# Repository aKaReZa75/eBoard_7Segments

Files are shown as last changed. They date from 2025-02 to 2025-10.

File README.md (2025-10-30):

# 7Segment Shield
This project involves designing, assembling, and testing an Arduino shield with a 7-segment display. The board includes a 7-segment display, push buttons, and an Oled display.

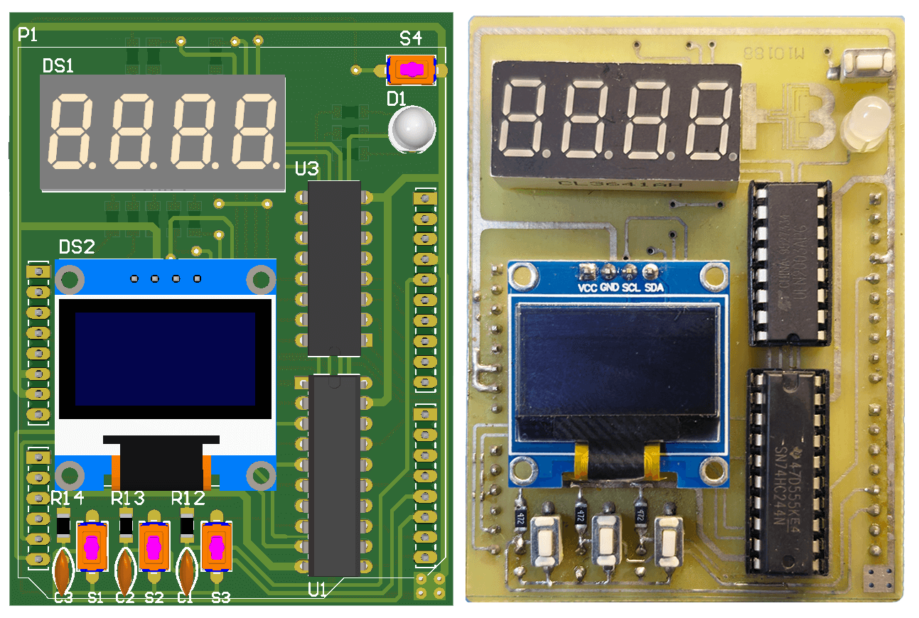
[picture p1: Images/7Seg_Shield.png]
7Segment Shield


> [!IMPORTANT]
> Before sending the board files for PCB fabrication, **always make sure you are using the latest released version** of the project.
> Hardware issues or design flaws might exist in earlier versions and could be fixed in newer releases.
> To avoid costly mistakes and ensure the best performance, always refer to the **[Releases](../../releases)** section, where all known issues, updates, and version-specific notes are clearly documented.

<table>
  <tr>
  <td valign="top">
  
  > [!TIP]  
  > If you're looking to better understand how to navigate and use my GitHub repositories — including exploring their structure, downloading or cloning projects, submitting issues, and asking questions,  
  > everything you need is clearly explained in this video:  
  > [aKaReZa 95 - Programming, Git - PART B](https://youtu.be/zYiUItVFRqQ)  
  > Make sure to check it out!
  
  </td>
    <td width="360" valign="middle" style="padding: 0;">
      <a href="https://youtu.be/zYiUItVFRqQ">
       aKaReZa 95 - Programming, Git - PART B Thumbnail
      </a>
    </td>
  </td>
  </tr>

<tr>
  <td valign="top">
  
  > [!IMPORTANT]
  > Begin your embedded systems journey with clarity and purpose. This episode outlines a structured roadmap for mastering microcontrollers, communication protocols, hardware design, and project development.  
  > Learn how to choose your specialization, follow curated playlists, and engage effectively with the community—ideal for learners seeking a scalable, goal-driven path into embedded engineering.  
  > [aKaReZa 124 – Embedded Systems Roadmap](https://youtu.be/3QYfv7A7aMc)  
  > Watch it now to kickstart your journey!
  
  </td>
  <td width="360" valign="middle" style="padding: 0;">
    <a href="https://youtu.be/3QYfv7A7aMc">
      aKaReZa 124 – Embedded Systems Roadmap Thumbnail
    </a>
  </td>
</tr>

  <tr>
  <td colspan="3">

  > [!CAUTION]
  > It is absolutely critical that you carefully read every single word of this document, line by line, to ensure you don't miss any details. Nothing can be overlooked.
      
  </td>
  </tr>  
</table>

## Detailed Description
| Aspect | Description |
|---|---|
| PCB Design Software  | Altium  V24.2.2 |
| PCB Layers | 2-Layer FR4 |
| Pin Type | Arduino UNO |
| 7Segment | CC - MPX4 - 30.2x14.1mm |
| Oled | SSD1306 - 0.96" - 128X64 - I2C |
| PushButtom | SMT Tactile 2PIN - SPST - 6X3X2 |

## **Pinout Mapping Table**
| **Shield Pin** | **Arduino Pin** | **ATmega328P Pin** | **STM32F103C8T6 Pin** |
| :---: | :---: | :---: | :---: |
| **Segment A (7-Segment)** | A0 | PC0 | PA0 |
| **Segment B (7-Segment)** | A1 | PC1 | PA1 |
| **Segment C (7-Segment)** | A2 | PC2 | PA2 |
| **Segment D (7-Segment)** | A3 | PC3 | PA3 |
| **Segment E (7-Segment)** | D0 | PD0 | PB11 |
| **Segment F (7-Segment)** | D1 | PD1 | PB10 |
| **Segment G (7-Segment)** | D4 | PD4 | PA7 |
| **Decimal Point (7-Segment)** | D7 | PD7 | PA9 |
|  **Digit 1 (Common Cathode)** | D8 | PB0 | PA15 |
|  **Digit 2 (Common Cathode)** | D9 | PB1 | PA8 |
|  **Digit 3 (Common Cathode)** | D10 | PB2 | PB12 |
|  **Digit 4 (Common Cathode)** | D12 | PB4 | PB14 |
| **Switch 1 (Active High)**  | D13 | PB5 | PB13 |
| **Switch 2 (Active High)**  | D3 | PD3 | PA6 |
| **Switch 3 (Active High)**  | D2 | PD2 | PB2 |
|  **RGB Green (Active High)**  | D5 | PD5 | PB0 |
| **RGB Blue (Active High)**  | D6 | PD6 | PB1 |
| **RGB RED (Active High)** | D11 | PB3 | PB15 |
| **Serial Data (SDA)** | A4 | PC4 | PB9 |
| **Serial Clock (SCL)** | A5 | PC5 | PB8 |

## Resources

> [!TIP]
> The resources are detailed in the sections below.  
> To access any of them, simply click on the corresponding blue link.

- [Altium Library](https://github.com/aKaReZa75/Altium-Library)  
  ---  
   All PCB designs across all repositories and projects are built using this Altium Designer component library. It contains a wide range of verified footprints, schematic symbols, and 3D models, ensuring consistency and accuracy in PCB designs. If you're working on a new PCB, using this library will save you time and minimize errors.

- [PCB & Electronics Design Training](https://github.com/aKaReZa75/PCB)  
  ---  
  This repository is dedicated to **learning PCB design and electronics from scratch**. It covers everything from circuit theory to practical PCB layout techniques, including routing strategies, best practices, and component placement. Whether you're a beginner or an experienced designer, this resource will help you **improve your PCB design skills and create professional-quality boards**.

- [Microcontroller Training](https://github.com/aKaReZa75/Microcontroller)  
  ---  
  This repository offers a comprehensive guide to learning **various microcontrollers** and how to interface them with different shields. You’ll find tutorials on **using and configuring shields**, along with hands-on projects to help you **get your microcontrollers up and running**. Whether you're working with **Arduino, STM32, ESP32**, or others, this resource will help you understand how to integrate these platforms effectively for your projects.

- [Shopping Link](./ShoppingLink.md)  
  ---
  This document provides links to trusted suppliers where you can purchase all the essential components for this project, ensuring quality and reliability.

```plaintext
Arduino Shields
   ├── [aKaReZa 36 - eBoard, 7Segment Shield - Part A]
   │   ├─ PCB Design — Two-layer Arduino shield with displays and buttons.
   │   ├─ Components — 74HC244, ULN2003, OLED, 7-segment, push buttons.
   │   └─ Layout — Schematic, placement, routing + Altium automation.
   │
   ├── [aKaReZa 40 - eBoard, 7Segment Shield - Part B]
   │   ├─ Troubleshooting — Routing issues and manual optimizations.
   │   └─ Review — Vias, GND problems, and connectivity fixes.
   │
   └── [aKaReZa 42 - Repair, Arduino 7Segment Shield Soldering]
       ├─ Assembly — Soldering tools, SMD + THD techniques.
       └── Components — ICs, buttons, displays, RGB LEDs, pin headers.
```     

## Project Videos
<table style="border-collapse: collapse;">
  <tr>
    <td valign="top" style="padding: 0 10px;">
      <h3 style="margin: 0;">
        <a href="https://youtu.be/BtFFsqzkCSk">aKaReZa 36 – PCB, 7Segment Shield - Part A</a>
      </h3>
      <p style="margin: 8px 0 0;">
        In this video, we design our first double-layer PCB. The board we design is an Arduino shield that includes a 7-segment display, push buttons, and an Oled display.
      </p>
    </td>
    <td width="360" valign="top" style="padding: 0;">
      <a href="https://youtu.be/BtFFsqzkCSk">
        aKaReZa 36 – PCB, 7Segment Shield - Part A Thumbnail
      </a>
    </td>
  </tr>

  <tr>
    <td valign="top" style="padding: 0 10px;">
      <h3 style="margin: 0;">
        <a href="https://youtu.be/yqlKacCi0RM">aKaReZa 40 – PCB, 7Segment Shield - Part B</a>
      </h3>
      <p style="margin: 8px 0 0;">
        In this video, we examine the issues with the 7-segment and Oled Arduino shield we designed in the previous video, which was routed using Auto Route. We review the problems and discuss manual routing along with important tips to follow during manual routing.
      </p>
    </td>
    <td width="360" valign="top" style="padding: 0;">
      <a href="https://youtu.be/yqlKacCi0RM">
        aKaReZa 40 – PCB, 7Segment Shield - Part B Thumbnail
      </a>
    </td>
  </tr>

  <tr>
    <td valign="top" style="padding: 0 10px;">
      <h3 style="margin: 0;">
        <a href="https://youtu.be/1Rpm_uHoqAg">aKaReZa 42 – Repair, Arduino 7Segment Shield Soldering</a>
      </h3>
      <p style="margin: 8px 0 0;">
        In this video, we assemble the 7-segment and OLED shield we designed after printing it, and we learn several important tips about proper soldering techniques for SMD and THD components.
      </p>
    </td>
    <td width="360" valign="top" style="padding: 0;">
      <a href="https://youtu.be/1Rpm_uHoqAg">
        aKaReZa 42 – Repair, Arduino 7Segment Shield Soldering Thumbnail
      </a>
    </td>
  </tr>
</table>

# 💻 How to Use Git and GitHub
To access the repository files and save them on your computer, there are two methods available:
1. **Using Git Bash and Cloning the Repository**
   - This method is more suitable for advanced users and those familiar with command-line tools.
   - By using this method, you can easily receive updates for the repository.

2. **Downloading the Repository as a ZIP file**
   - This method is simpler and suitable for users who are not comfortable with command-line tools.
   - Note that with this method, you will not automatically receive updates for the repository and will need to manually download any new updates.

## Clone using the URL.
First, open **Git Bash** :
-  Open the folder in **File Explorer** where you want the library to be stored.
-  **Right-click** inside the folder and select the option **"Open Git Bash here"** to open **Git Bash** in that directory.

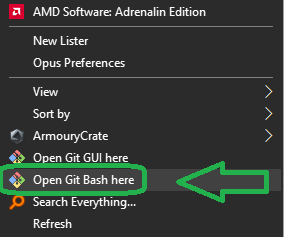
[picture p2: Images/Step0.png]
open Git Bash


> [!NOTE] 
> If you do not see the "Open Git Bash here" option, it means that Git is not installed on your system.  
> You can download and install Git from [this link](https://git-scm.com/downloads).  
> For a tutorial on how to install and use Git, check out [this video](https://youtu.be/BsykgHpmUt8).
  
-  Once **Git Bash** is open, run the following command to clone the repository:

 ```bash
git clone https://github.com/aKaReZa75/eBoard_7Segments.git
```
- You can copy the above command by either:
- Clicking on the **Copy** button on the right of the command.
- Or select the command text manually and press **Ctrl + C** to copy.
- To paste the command into your **Git Bash** terminal, use **Shift + Insert**.

Clone the Repository

- Then, press Enter to start the cloning operation and wait for the success message to appear.

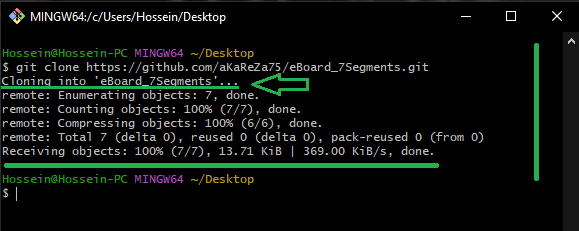
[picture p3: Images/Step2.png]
Open the Library File


> [!IMPORTANT]
> Please keep in mind that the numbers displayed in the image might vary when you perform the same actions.  
> This is because repositories are continuously being updated and expanded. Nevertheless, the overall process remains unchanged.

> [!NOTE]
> Advantage of Cloning the Repository:  
> - **Receiving Updates:** By cloning the repository, you can easily and automatically receive new updates.  
> - **Version Control:** Using Git allows you to track changes and revert to previous versions.  
> - **Team Collaboration:** If you are working on a project with a team, you can easily sync changes from team members and collaborate more efficiently.  

## Download Zip
If you prefer not to use Git Bash or the command line, you can download the repository directly from GitHub as a ZIP file.  
Follow these steps:  
1. Navigate to the GitHub repository page and Locate the Code button:
- On the main page of the repository, you will see a green Code button near the top right corner.

2. Download the repository:
- Click the Code button to open a dropdown menu.
- Select Download ZIP from the menu.

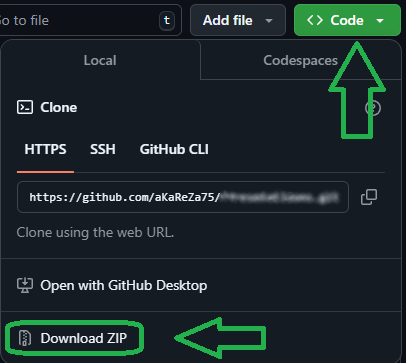
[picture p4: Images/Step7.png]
Download Zip
    

3. Save the ZIP file:
- Choose a location on your computer to save the ZIP file and click Save.

4. Extract the ZIP file:
- Navigate to the folder where you saved the ZIP file.
- Right-click on the ZIP file and select Extract All... (Windows) or use your preferred extraction tool.
- Choose a destination folder and extract the contents.

5. Access the repository:
- Once extracted, you can access the repository files in the destination folder.

> [!IMPORTANT]
> - No Updates: Keep in mind that downloading the repository as a ZIP file does not allow you to receive updates.    
>   If the repository is updated, you will need to download it again manually.  
> - Ease of Use: This method is simpler and suitable for users who are not comfortable with Git or command-line tools.

# 📝 How to Ask Questions
If you have any questions or issues, you can raise them through the **"Issues"** section of this repository. Here's how you can do it:  

1. Navigate to the **"Issues"** tab at the top of the repository page.  

  Issues

2. Click on the **"New Issue"** button.  
   
  New Issue

3. In the **Title** field, write a short summary of your issue or question.  

4. In the "Description" field, detail your question or issue as thoroughly as possible. You can use text formatting, attach files, and assign the issue to someone if needed. You can also use text formatting (like bullet points or code snippets) for better readability.  

5. Optionally, you can add **labels**, **type**, **projects**, or **milestones** to your issue for better categorization.  

6. Click on the **"Submit new issue"** button to post your question or issue.
   
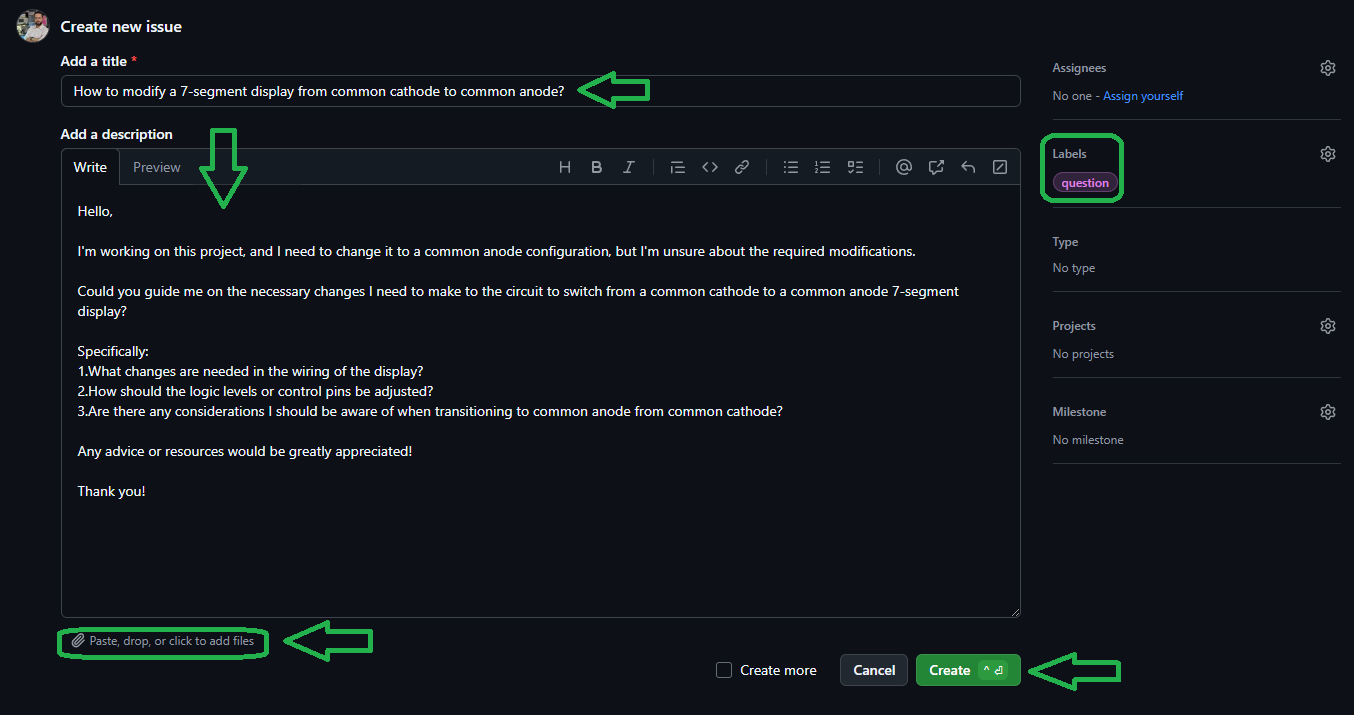
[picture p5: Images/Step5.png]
Submeet New Issue
  

I will review and respond to your issue as soon as possible. Your participation helps improve the repository for everyone!  

> [!TIP]
> - Before creating a new issue, please check the **"Closed"** section to see if your question has already been answered.  
>   Closed section  
> - Write your question clearly and respectfully to ensure a faster and better response.  
> - While the examples provided above are in English, feel free to ask your questions in **Persian (فارسی)** as well.  
> - There is no difference in how they will be handled!  

> [!NOTE]
> Pages and interfaces may change over time, but the steps to create an issue generally remain the same.

# 🤝 Contributing to the Repository
To contribute to this repository, please follow these steps:
1. **Fork the Repository**  
2. **Clone the Forked Repository**  
3. **Create a New Branch**  
4. **Make Your Changes**  
5. **Commit Your Changes**  
6. **Push Your Changes to Your Forked Repository**  
7. **Submit a Pull Request (PR)**  

> [!NOTE]
> Please ensure your pull request includes a clear description of the changes you’ve made.
> Once submitted, I will review your contribution and provide feedback if necessary.

# 🌟 Support Me
If you found this repository useful:
- Subscribe to my [YouTube Channel](https://www.youtube.com/@aKaReZa75).
- Share this repository with others.
- Give this repository and my other repositories a star.
- Follow my [GitHub account](https://github.com/aKaReZa75).

# 📜 License
This project is licensed under the GPL-3.0 License. This license grants you the freedom to use, modify, and distribute the project as long as you:
- Credit the original authors: Give proper attribution to the original creators.
- Disclose source code: If you distribute a modified version, you must make the source code available under the same GPL license.
- Maintain the same license: When you distribute derivative works, they must be licensed under the GPL-3.0 too.
- Feel free to use it in your projects, but make sure to comply with the terms of this license.
  
# ✉️ Contact Me
Feel free to reach out to me through any of the following platforms:
- 📧 [Email: aKaReZa75@gmail.com](mailto:aKaReZa75@gmail.com)
- 🎥 [YouTube: @aKaReZa75](https://www.youtube.com/@aKaReZa75)
- 💼 [LinkedIn: @akareza75](https://www.linkedin.com/in/akareza75)

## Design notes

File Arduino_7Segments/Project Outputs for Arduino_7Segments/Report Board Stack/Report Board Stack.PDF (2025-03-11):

# Board Stack Report

Stack Up | Layer Stack
Layer | Board Layer Stack | Name | Material | Thickness Constant Dk | | | Coverlay expansion | Orientation | Copper Orientation
1 | | Top Overlay | | 0mm
2 | | Top Solder | Solder Resist | 0.01016mm | 3.5 | 3.5 0mm
3 | | Top Layer | | 0.03556mm | | | | BodyUp | Above
4 | | Dielectric 1 | FR-4 | 1.5mm | 4.8 | 4.8
5 | | Bottom Layer | | 0.03556mm | | | | BodyDown | Below
6 | | Bottom Solder | Solder Resist | 0.01016mm | 3.5 | 3.5 0mm
7 | | Bottom Overlay | | 0mm
| Height : 1.59144mm

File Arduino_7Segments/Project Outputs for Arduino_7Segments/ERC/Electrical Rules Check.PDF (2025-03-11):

### Electrical Rules Check Report

Class | Document | Message Successful Compile for Arduino_7Segments.PrjPcb
Tuesday 11 Mar 2025 1:01:06 PM | Page 1 of 1

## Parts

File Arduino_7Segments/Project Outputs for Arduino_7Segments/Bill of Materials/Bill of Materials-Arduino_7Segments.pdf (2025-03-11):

Altium Limited Confidential | 3/11/2025 | Page 1

# Bill of Materials

Title: Bill of Materials for Project [Arduino_7Segments.PrjPcb] (No PCB Document Selected) Project: 7Segment Shield
Company github.com/aKaReZa75
Variant: None
Revision: 1.0
Inflow | LibRef | Footprint | Value | Rating | Package | Type | Description | Comment | Quantity
inflow? | Cap_Multi_THT | Cap - 100nF | 100n | Rating? | Package? | Type? | Multi layer capacitor | 100n | 3
1506 | IC_Driver_ULN2003 | CDIP16 | ULN2003 | Rating? | SO-16 | Driver | Seven darlington array drivers | ULN2003 | 1
1118 | IC_Logic_74HCT244 | PDIP20 | 74HCT244 | 8b | Dip | 3-State Non- | Octal Bus Buffer with 3 State Outputs | 74HCT244 | 1
8128 | ModSen_7Seg_MPX4_CC | 7Seg-MPX4-30.2x14.1mm | 4Digit, Red | Rating? | Package? | Type? | 7Segment-MPX4-CC | 4Digit, Red | 1
inflow? | ModSen_LCD_Oled_0.96_2 | OLED_SSD1306_64_I2C | SSD1306 | 128x64 | 0.96 | OLED | Oled Display | SSD1306 | 1
inflow? | Res_SMD_1206 | RES 1206 (3216X08L) | 4.7K | 0.25W | 1206 | 10% | Resistor | 4.7K | 5
inflow? | Res_SMD_1206 | RES 1206 (3216X08L) | 470b | 0.25W | 1206 | 10% | Resistor | 470b | 11
5139 | Semi_LED_RGB_THT | RGB_DIP | RGB | 5V | Dip | CA | SMD 5050 LED RGB and Other | RGB | 1
8260 | SW_PushButton_2_SMD | SW_PB_SMD_2PIN_SPST_6X | PB | 2b | SMD | Vertical | SMT Tactile ‎Switch | PB | 4
Approved Notes | | | | | | | | | 28

3/11/2025 1:01 PM
Hossein Bagheri

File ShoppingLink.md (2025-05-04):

# 📦 Components Purchase Links
This section provides a comprehensive list of components required for the "7Segment Shield" project.
Each item includes direct purchase links from reliable Iranian electronics suppliers, with recommended quantities for both essential needs and future prototyping.

## Capacitor
- [ ] [**Cap_Ceramic_100n**](https://roboeq.ir/products/detail/0301031/%D8%AE%D8%A7%D8%B2%D9%86-100-%D9%86%D8%A7%D9%86%D9%88-%D9%81%D8%A7%D8%B1%D8%A7%D8%AF-%D8%B9%D8%AF%D8%B3%DB%8C/) Quantity: 3, Prefer: 10, Supplier: RoboEq

## Connector
- [ ] [**Male_PinHeader**](https://roboeq.ir/products/detail/1504006/%D9%BE%DB%8C%D9%86-%D9%87%D8%AF%D8%B1-401-%D8%B5%D8%A7%D9%81-%D9%86%D8%B1%DB%8C-11-%D9%85%DB%8C%D9%84%DB%8C-%D9%85%D8%AA%D8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) Quantity: 1, Prefer: 1, Supplier: RoboEq
- [ ] [**PLCC_16**](https://roboeq.ir/products/detail/1501004/%D8%B3%D9%88%DA%A9%D8%AA-16-%D9%BE%DB%8C%D9%86/) Quantity: 1, Prefer: 5, Supplier: RoboEq
- [ ] [**PLCC_20**](https://roboeq.ir/products/detail/1501012/%D8%B3%D9%88%DA%A9%D8%AA-20-%D9%BE%DB%8C%D9%86/) Quantity: 1, Prefer: 5, Supplier: RoboEq

## Integrated Circuit
- [ ] [**IC_ULN2003_THT**](https://roboeq.ir/products/detail/0318002/%D8%AF%D8%B1%D8%A7%DB%8C%D9%88%D8%B1-ULN2003L-/) Quantity: 1, Prefer: 1, Supplier: RoboEq  
- [ ] [**IC_74HCT244_THT**](https://roboeq.ir/products/detail/0311015/%D8%A2%DB%8C-%D8%B3%DB%8C-%D8%A8%D8%A7%D9%81%D8%B1-%D8%B3%D9%87-%D8%AD%D8%A7%D9%84%D8%AA%D9%87-74HC244/) Quantity: 1, Prefer: 1, Supplier: RoboEq  

## Module and Sensor
- [ ] [**7Seg_MPX4_CC**](https://roboeq.ir/products/detail/1203013/%D8%B3%D9%88%D9%86-%D8%B3%DA%AF%D9%85%D9%86%D8%AA-%DA%86%D9%87%D8%A7%D8%B1-%D8%AA%D8%A7%DB%8C%DB%8C-%DA%A9%D8%A7%D8%AA%D8%A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) Quantity: 1, Prefer: 1, Supplier: RoboEQ
- [ ] [**Oled_0.96_I2C**](https://thecaferobot.com/store/0-96-inch-yellowblue-color-i2c-communication-12864-oled-lcd-module) Quantity: 1, Prefer: 1, Supplier: CafeRobot

## Resistor
- [ ] [**Res_1206_470b**](https://roboeq.ir/products/detail/0302655/%D9%85%D9%82%D8%A7%D9%88%D9%85%D8%AA-470-%D8%A7%D9%87%D9%85-SMD-1206/) Quantity: 11, Prefer: 25, Supplier: RoboEQ
- [ ] [**Res_1206_4.7K**](https://roboeq.ir/products/detail/3302344/%D9%85%D9%82%D8%A7%D9%88%D9%85%D8%AA-4-7-%DA%A9%DB%8C%D9%84%D9%88-%D8%A7%D9%87%D9%85-1206-SMD/) Quantity: 5, Prefer: 25, Supplier: RoboEQ

## Semiconductore
- [ ] [**LED_THT_RGB_CA**](https://roboeq.ir/products/detail/1202679/%D8%A7%D9%84-%D8%A7%DB%8C-%D8%AF%DB%8C-5-%D9%85%DB%8C%D9%84%DB%8C-%D9%85%D8%AA%D8%B1-%D9%85%D8%A7%D8%AA-RGB-%D8%A2%D9%86%D8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) Quantity: 1, Prefer: 5, Supplier: RoboEQ

## Switch
- [ ] [**SW_PushButton-6-3.5-2.5**](https://roboeq.ir/products/detail/1502082/%D8%AA%DA%A9-%D8%B3%D9%88%D8%A6%DB%8C%DA%86-6x3-5x2-5-%D8%AF%D9%88-%D9%BE%DB%8C%D9%86-SMD/) Quantity: 4, Prefer: 10, Supplier: RoboEQ

# 🌟 Support Me
If you found this repository useful:
- Subscribe to my [YouTube Channel](https://www.youtube.com/@aKaReZa75).
- Share this repository with others.
- Give this repository and my other repositories a star.
- Follow my [GitHub account](https://github.com/aKaReZa75).

# ✉️ Contact Me
Feel free to reach out to me through any of the following platforms:
- 📧 [Email: aKaReZa75@gmail.com](mailto:aKaReZa75@gmail.com)
- 🎥 [YouTube: @aKaReZa75](https://www.youtube.com/@aKaReZa75)
- 💼 [LinkedIn: @akareza75](https://www.linkedin.com/in/akareza75)

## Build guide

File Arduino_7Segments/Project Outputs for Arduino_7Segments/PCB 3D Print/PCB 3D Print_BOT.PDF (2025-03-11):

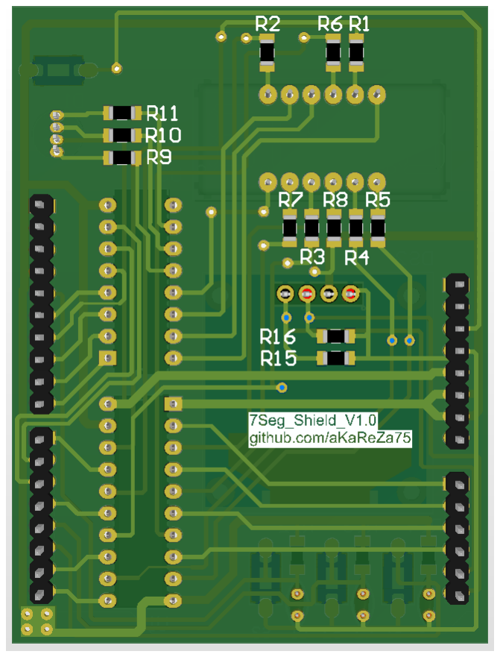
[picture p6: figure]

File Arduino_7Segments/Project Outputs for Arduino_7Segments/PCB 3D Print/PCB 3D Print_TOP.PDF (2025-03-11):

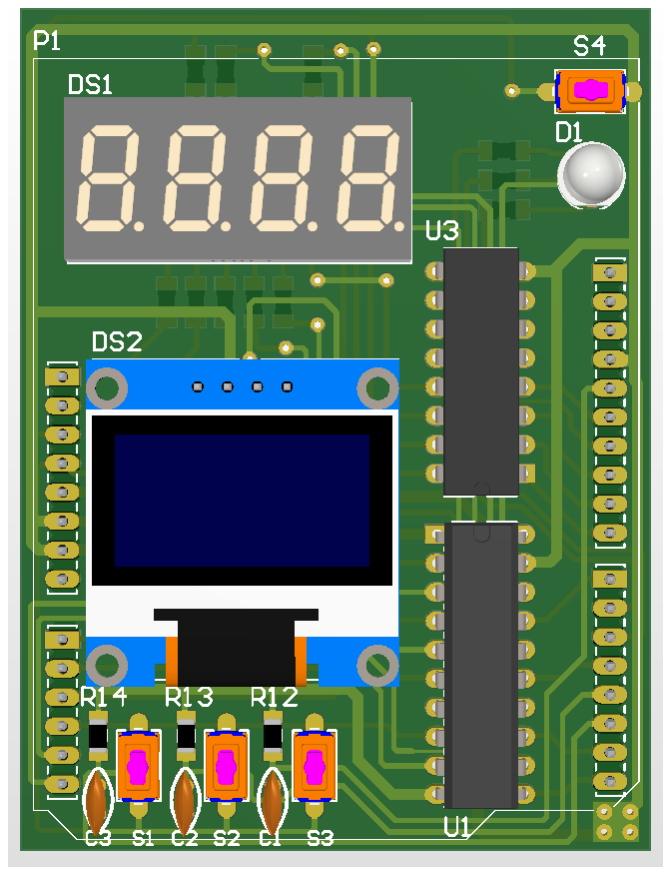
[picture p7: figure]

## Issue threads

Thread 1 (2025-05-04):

اصلاح قطعات و BOM

aKaReZa75, 2025-05-04:
1.توضیحات ال ای دی D1 صحیح نیست و باید از داخل کتابخانه اصلاح بشه
2. جای گذاری خازنهای C1-C2-C3 باید تغییر کنه و بره زیر برد که مانع فشرده شدن کلید نشن.

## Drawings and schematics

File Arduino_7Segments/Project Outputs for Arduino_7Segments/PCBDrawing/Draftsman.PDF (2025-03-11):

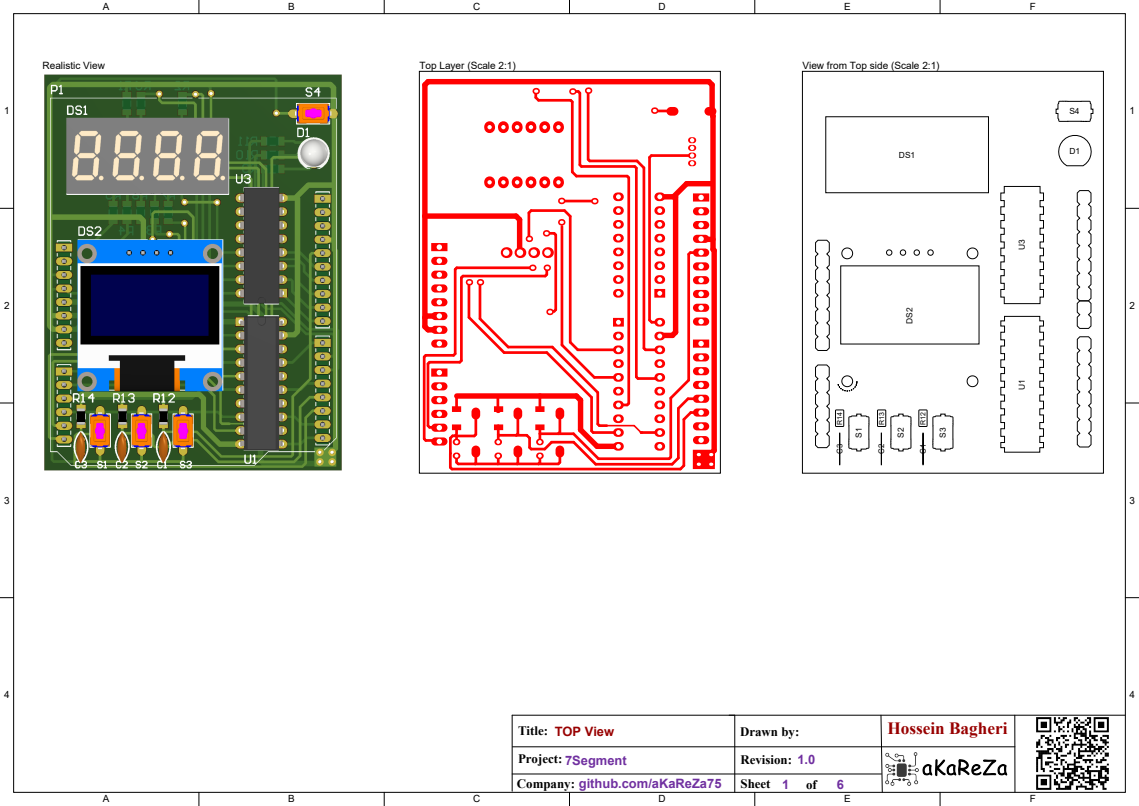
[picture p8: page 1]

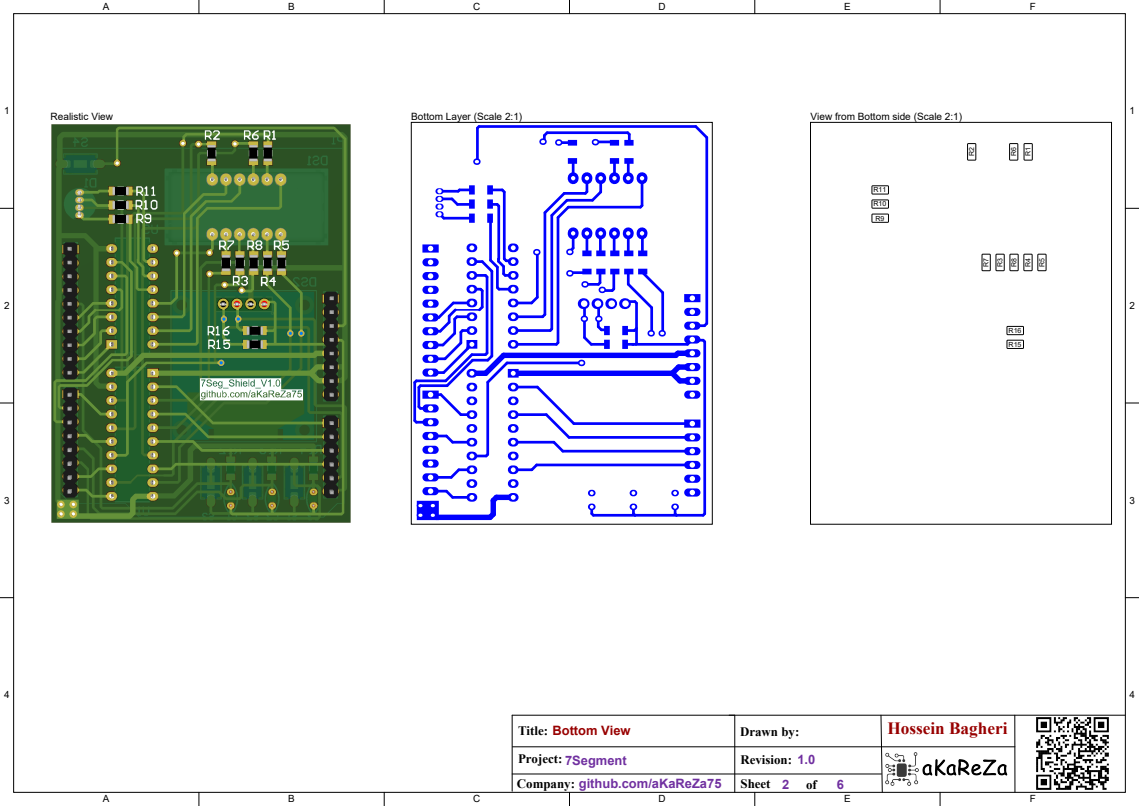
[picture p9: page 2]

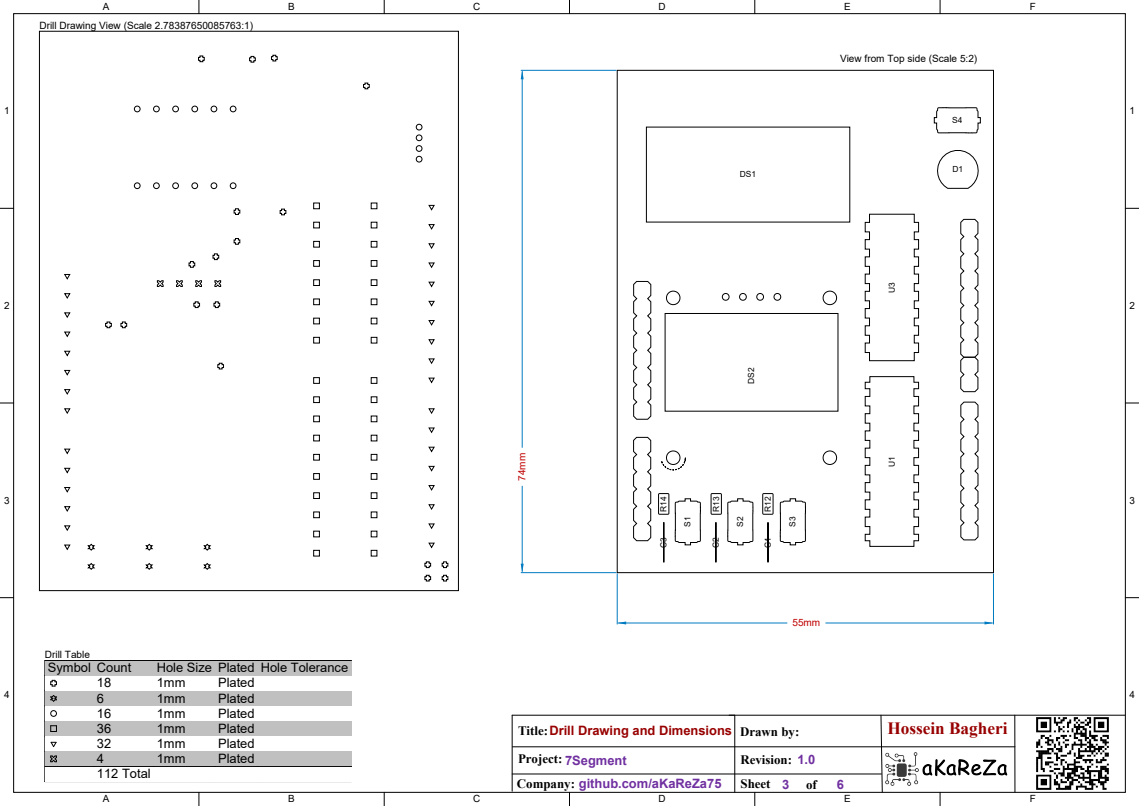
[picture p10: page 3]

Drill Drawing View (Scale 2.78387650085763:1)

View from Top side (Scale 5:2)

Symbol | Count | Hole Size | Plated | Hole Tolerance

18 | 1mm | Plated
6 | 1mm | Plated
16 | 1mm | Plated
36 | 1mm | Plated
32 | 1mm | Plated
4 | 1mm | Plated
112 Total

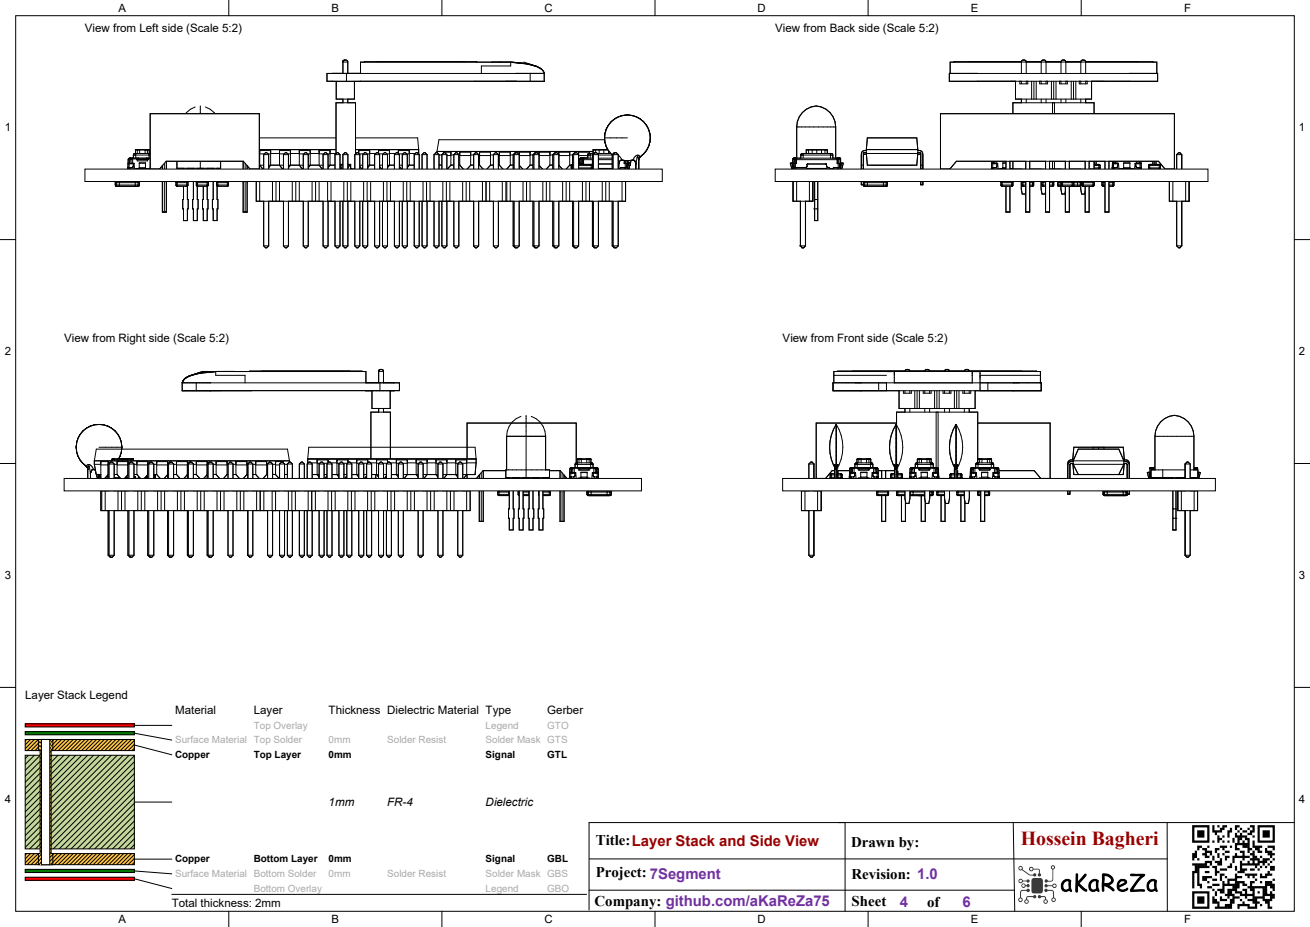
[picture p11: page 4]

View from Left side (Scale 5:2)

View from Back side (Scale 5:2)

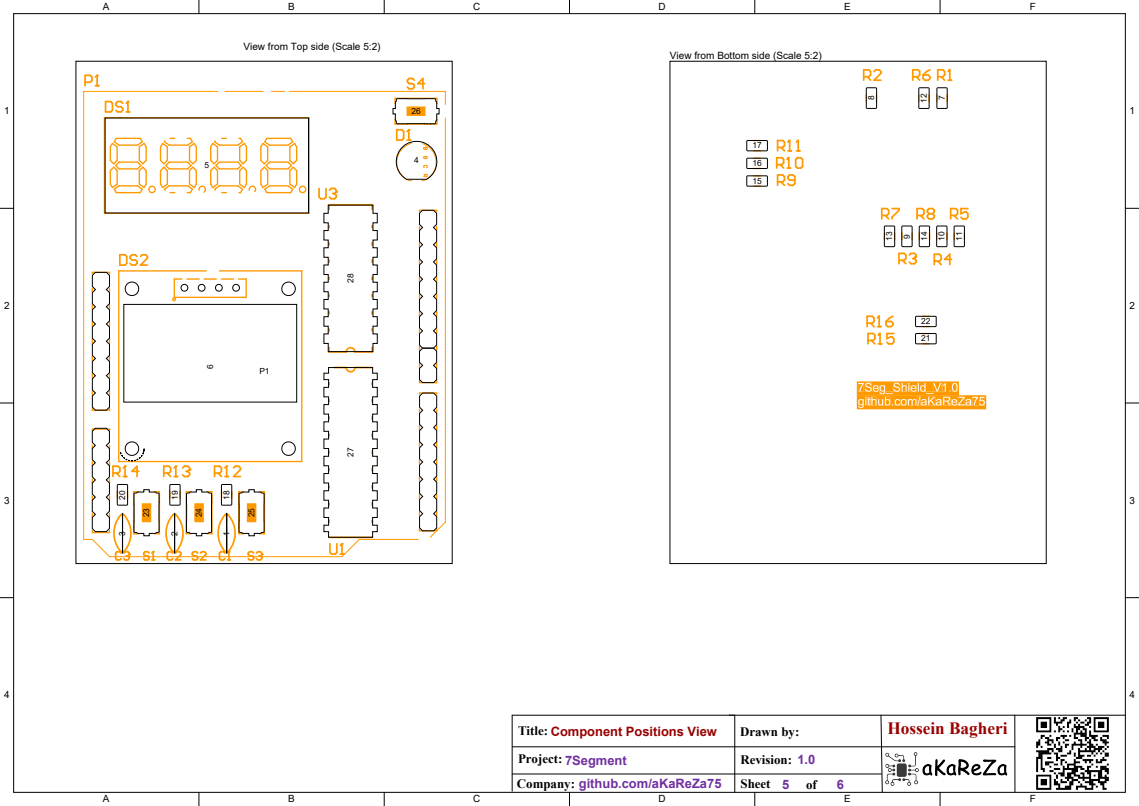
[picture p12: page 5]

View from Top side (Scale 5:2)

View from Bottom side (Scale 5:2)

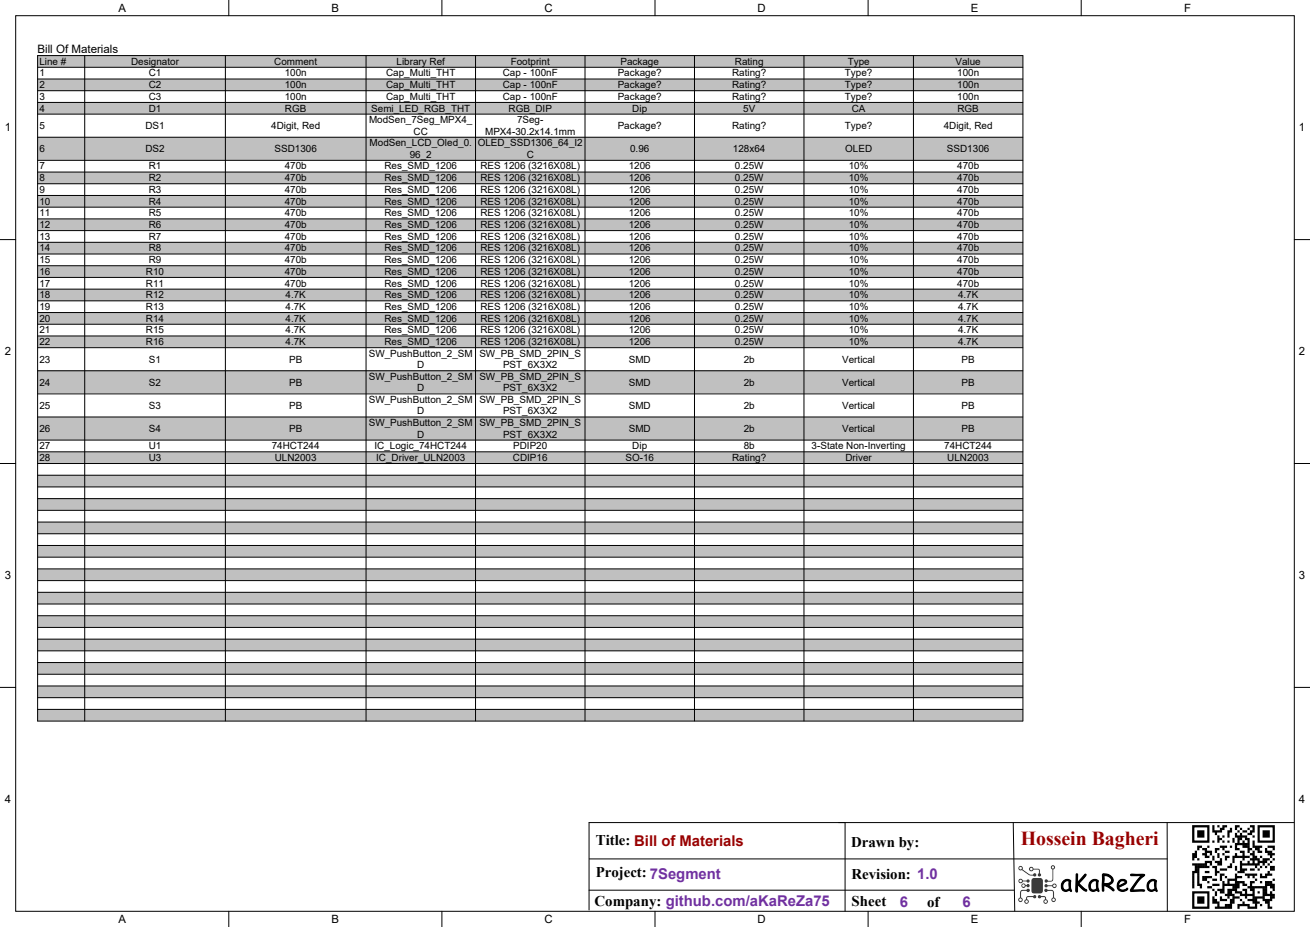
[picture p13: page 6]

Line # | Designator | Comment | Library Ref | Footprint | Package | Rating | Type | Value
1 | C1 | 100n | Cap_Multi_THT | Cap - 100nF | Package? | Rating? | Type? | 100n
2 | C2 | 100n | Cap_Multi_THT | Cap - 100nF | Package? | Rating? | Type? | 100n
3 | C3 | 100n | Cap_Multi_THT | Cap - 100nF | Package? | Rating? | Type? | 100n
4 | D1 | RGB | Semi_LED_RGB_THT | RGB_DIP | Dip | 5V | CA | RGB
5 | DS1 | 4Digit, Red | ModSen_7Seg_MPX4_ CC | 7Seg-MPX4-30.2x14.1mm | Package? | Rating? | Type? | 4Digit, Red

6 | DS2 | SSD1306 | ModSen_LCD_Oled_0. 96_2 | OLED_SSD1306_64_I2 C | 0.96 | 128x64 | OLED | SSD1306

7 | R1 | 470b | Res_SMD_1206 | RES 1206 (3216X08L) | 1206 | 0.25W | 10% | 470b
8 | R2 | 470b | Res_SMD_1206 | RES 1206 (3216X08L) | 1206 | 0.25W | 10% | 470b
9 | R3 | 470b | Res_SMD_1206 | RES 1206 (3216X08L) | 1206 | 0.25W | 10% | 470b
10 | R4 | 470b | Res_SMD_1206 | RES 1206 (3216X08L) | 1206 | 0.25W | 10% | 470b
11 | R5 | 470b | Res_SMD_1206 | RES 1206 (3216X08L) | 1206 | 0.25W | 10% | 470b
12 | R6 | 470b | Res_SMD_1206 | RES 1206 (3216X08L) | 1206 | 0.25W | 10% | 470b
13 | R7 | 470b | Res_SMD_1206 | RES 1206 (3216X08L) | 1206 | 0.25W | 10% | 470b
14 | R8 | 470b | Res_SMD_1206 | RES 1206 (3216X08L) | 1206 | 0.25W | 10% | 470b
15 | R9 | 470b | Res_SMD_1206 | RES 1206 (3216X08L) | 1206 | 0.25W | 10% | 470b
16 | R10 | 470b | Res_SMD_1206 | RES 1206 (3216X08L) | 1206 | 0.25W | 10% | 470b
17 | R11 | 470b | Res_SMD_1206 | RES 1206 (3216X08L) | 1206 | 0.25W | 10% | 470b
18 | R12 | 4.7K | Res_SMD_1206 | RES 1206 (3216X08L) | 1206 | 0.25W | 10% | 4.7K
19 | R13 | 4.7K | Res_SMD_1206 | RES 1206 (3216X08L) | 1206 | 0.25W | 10% | 4.7K
20 | R14 | 4.7K | Res_SMD_1206 | RES 1206 (3216X08L) | 1206 | 0.25W | 10% | 4.7K
21 | R15 | 4.7K | Res_SMD_1206 | RES 1206 (3216X08L) | 1206 | 0.25W | 10% | 4.7K
22 | R16 | 4.7K | Res_SMD_1206 | RES 1206 (3216X08L) | 1206 | 0.25W | 10% | 4.7K
23 | S1 | PB | SW_PushButton_2_SM D | SW_PB_SMD_2PIN_S PST_6X3X2 | SMD | 2b | Vertical | PB

24 | S2 | PB | SW_PushButton_2_SM D | SW_PB_SMD_2PIN_S PST_6X3X2 | SMD | 2b | Vertical | PB

25 | S3 | PB | SW_PushButton_2_SM D | SW_PB_SMD_2PIN_S PST_6X3X2 | SMD | 2b | Vertical | PB

26 | S4 | PB | SW_PushButton_2_SM D | SW_PB_SMD_2PIN_S PST_6X3X2 | SMD | 2b | Vertical | PB

27 | U1 | 74HCT244 | IC_Logic_74HCT244 | PDIP20 | Dip | 8b | 3-State Non-Inverting | 74HCT244
28 | U3 | ULN2003 | IC_Driver_ULN2003 | CDIP16 | SO-16 | Rating? | Driver | ULN2003

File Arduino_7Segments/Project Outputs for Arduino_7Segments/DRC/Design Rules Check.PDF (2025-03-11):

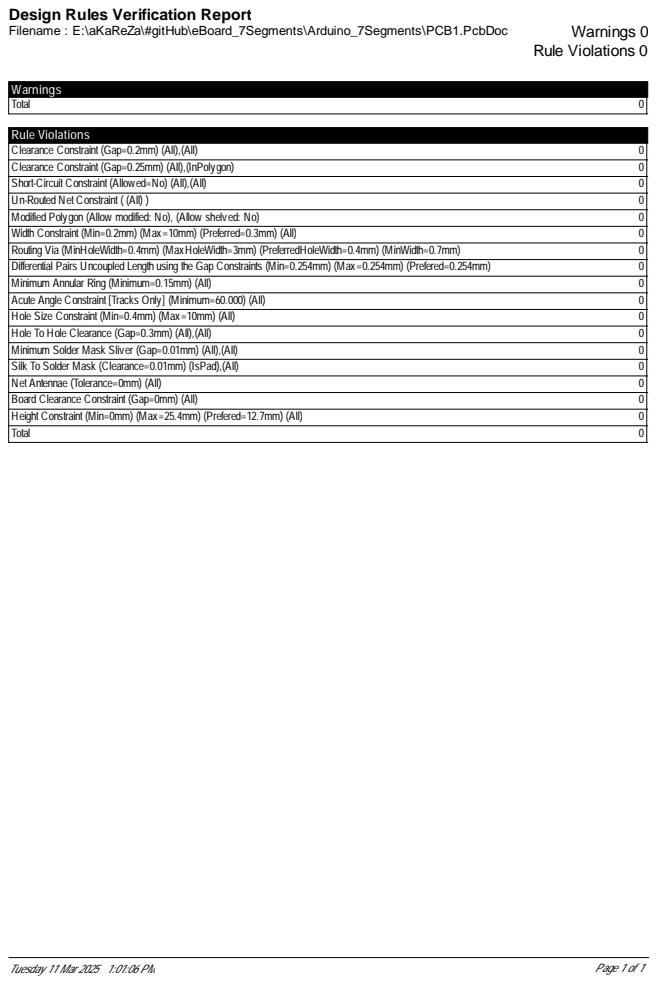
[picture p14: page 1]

Design Rules Verification Report

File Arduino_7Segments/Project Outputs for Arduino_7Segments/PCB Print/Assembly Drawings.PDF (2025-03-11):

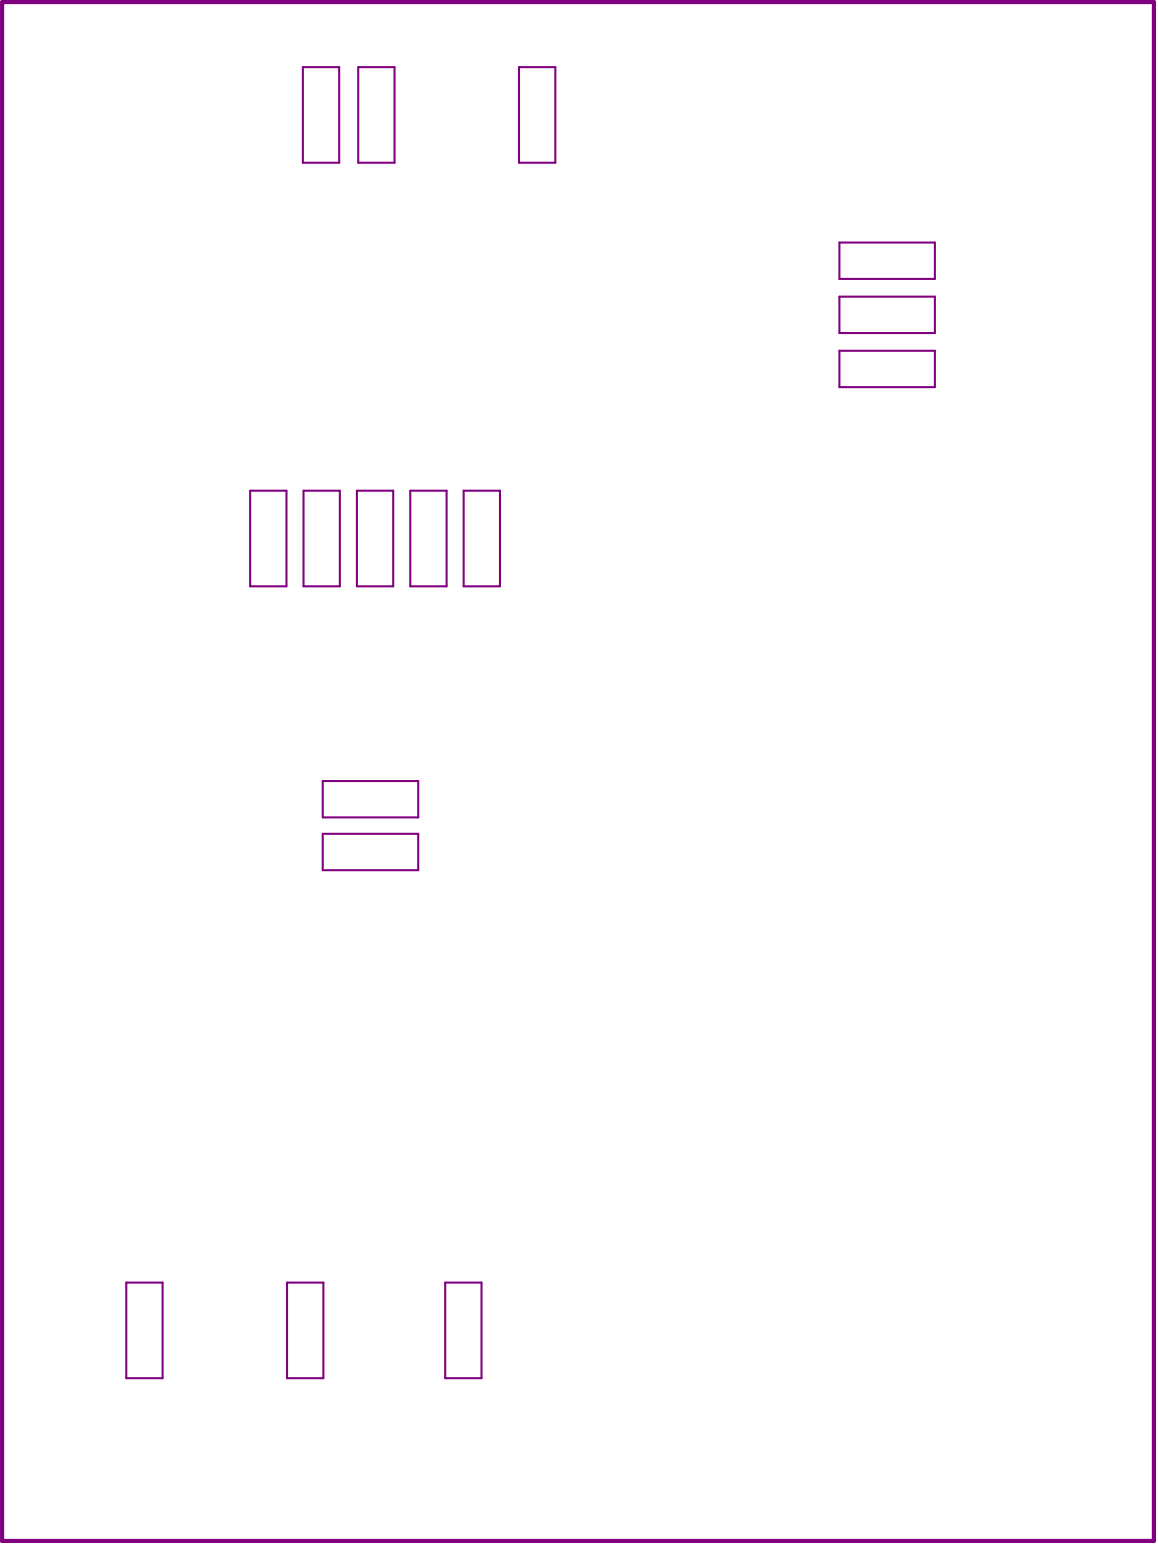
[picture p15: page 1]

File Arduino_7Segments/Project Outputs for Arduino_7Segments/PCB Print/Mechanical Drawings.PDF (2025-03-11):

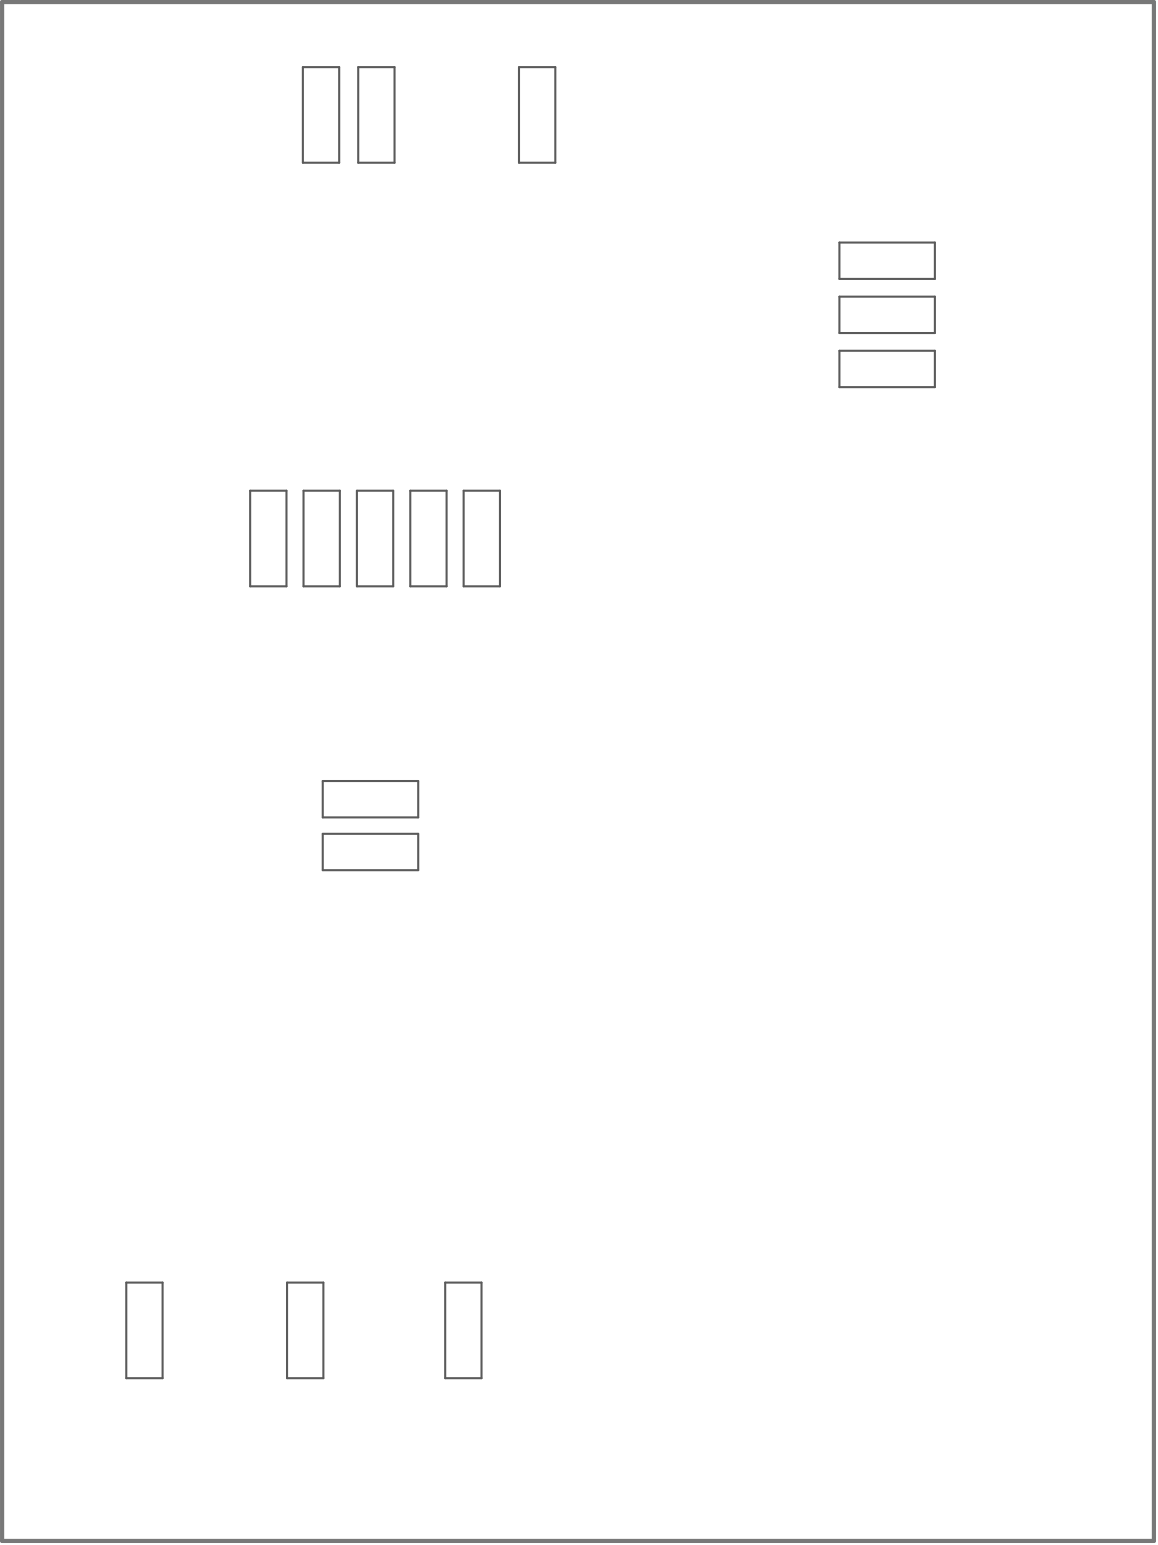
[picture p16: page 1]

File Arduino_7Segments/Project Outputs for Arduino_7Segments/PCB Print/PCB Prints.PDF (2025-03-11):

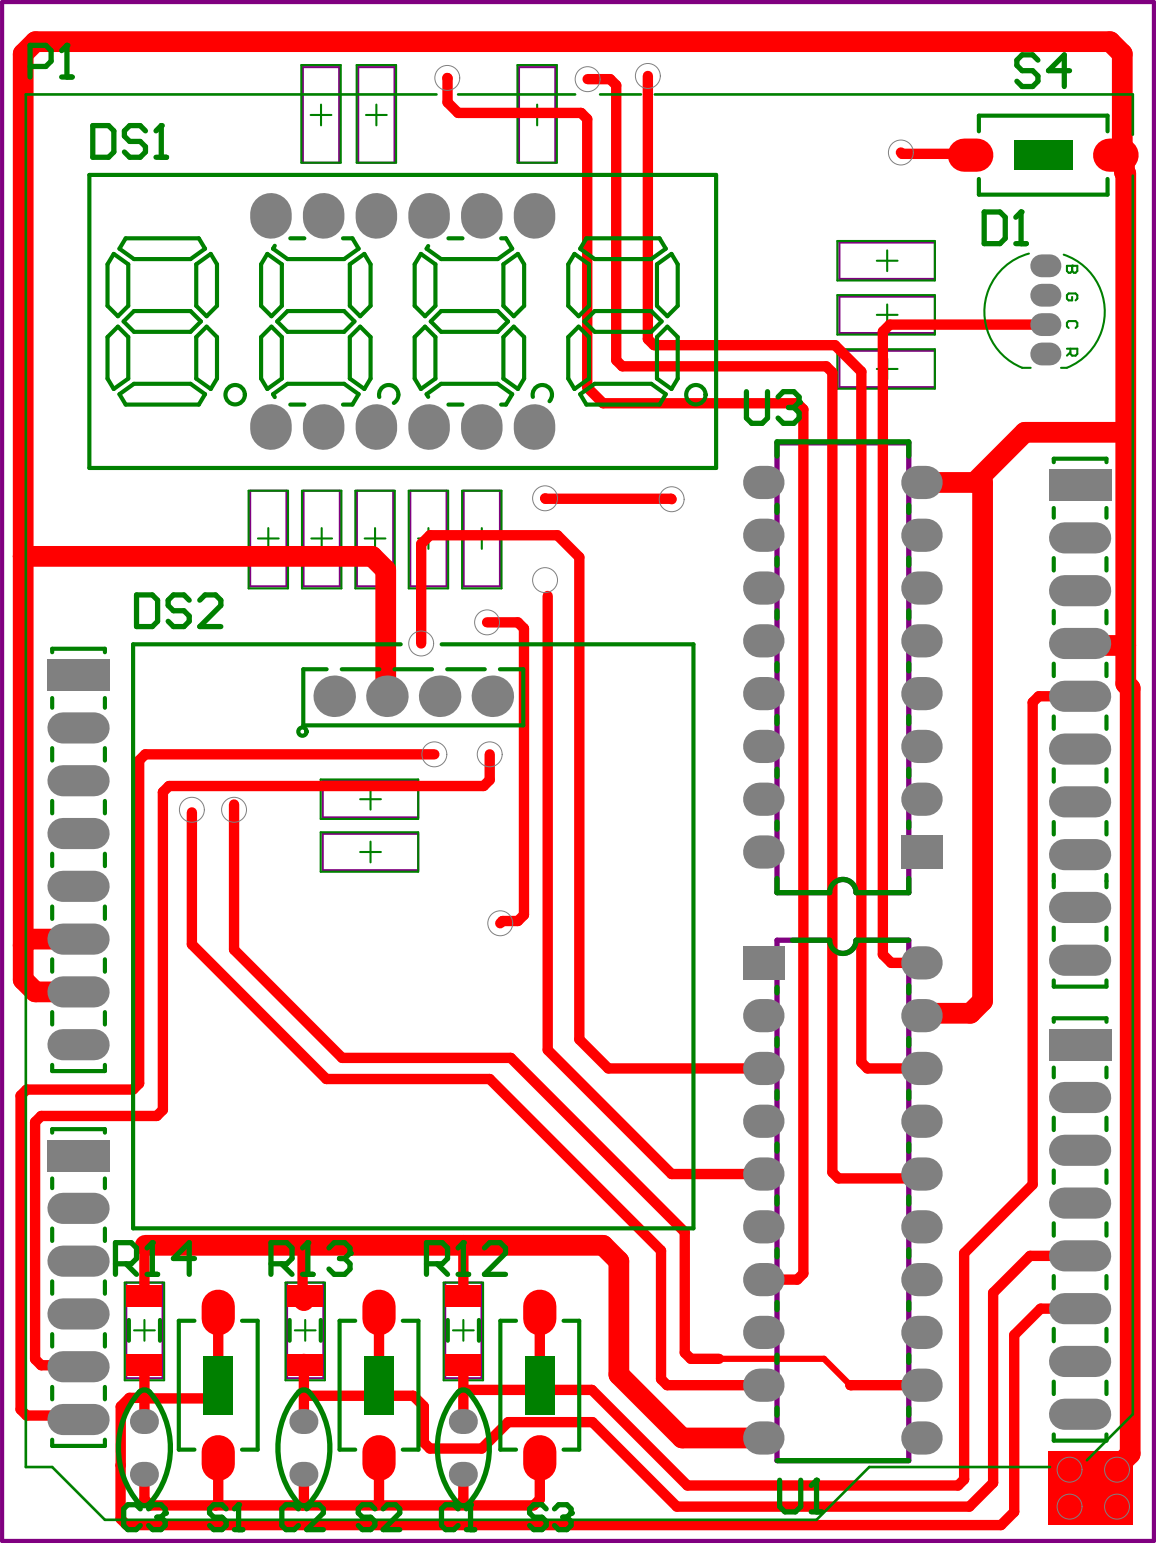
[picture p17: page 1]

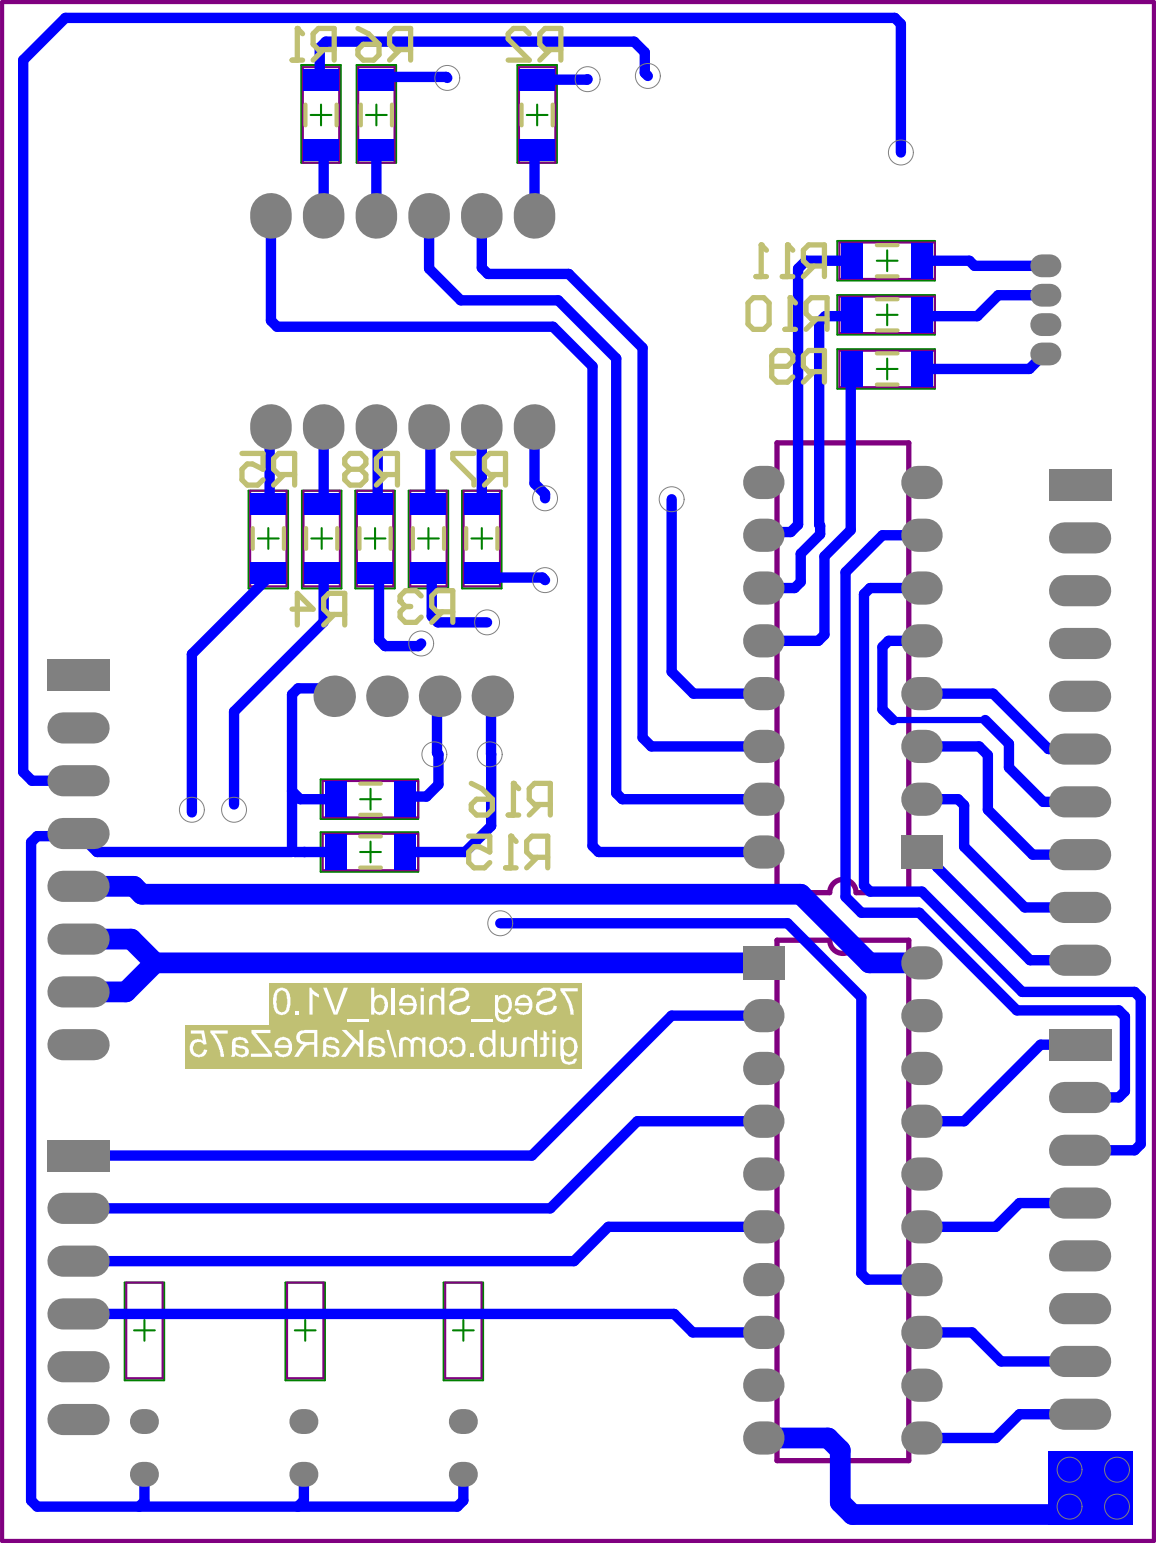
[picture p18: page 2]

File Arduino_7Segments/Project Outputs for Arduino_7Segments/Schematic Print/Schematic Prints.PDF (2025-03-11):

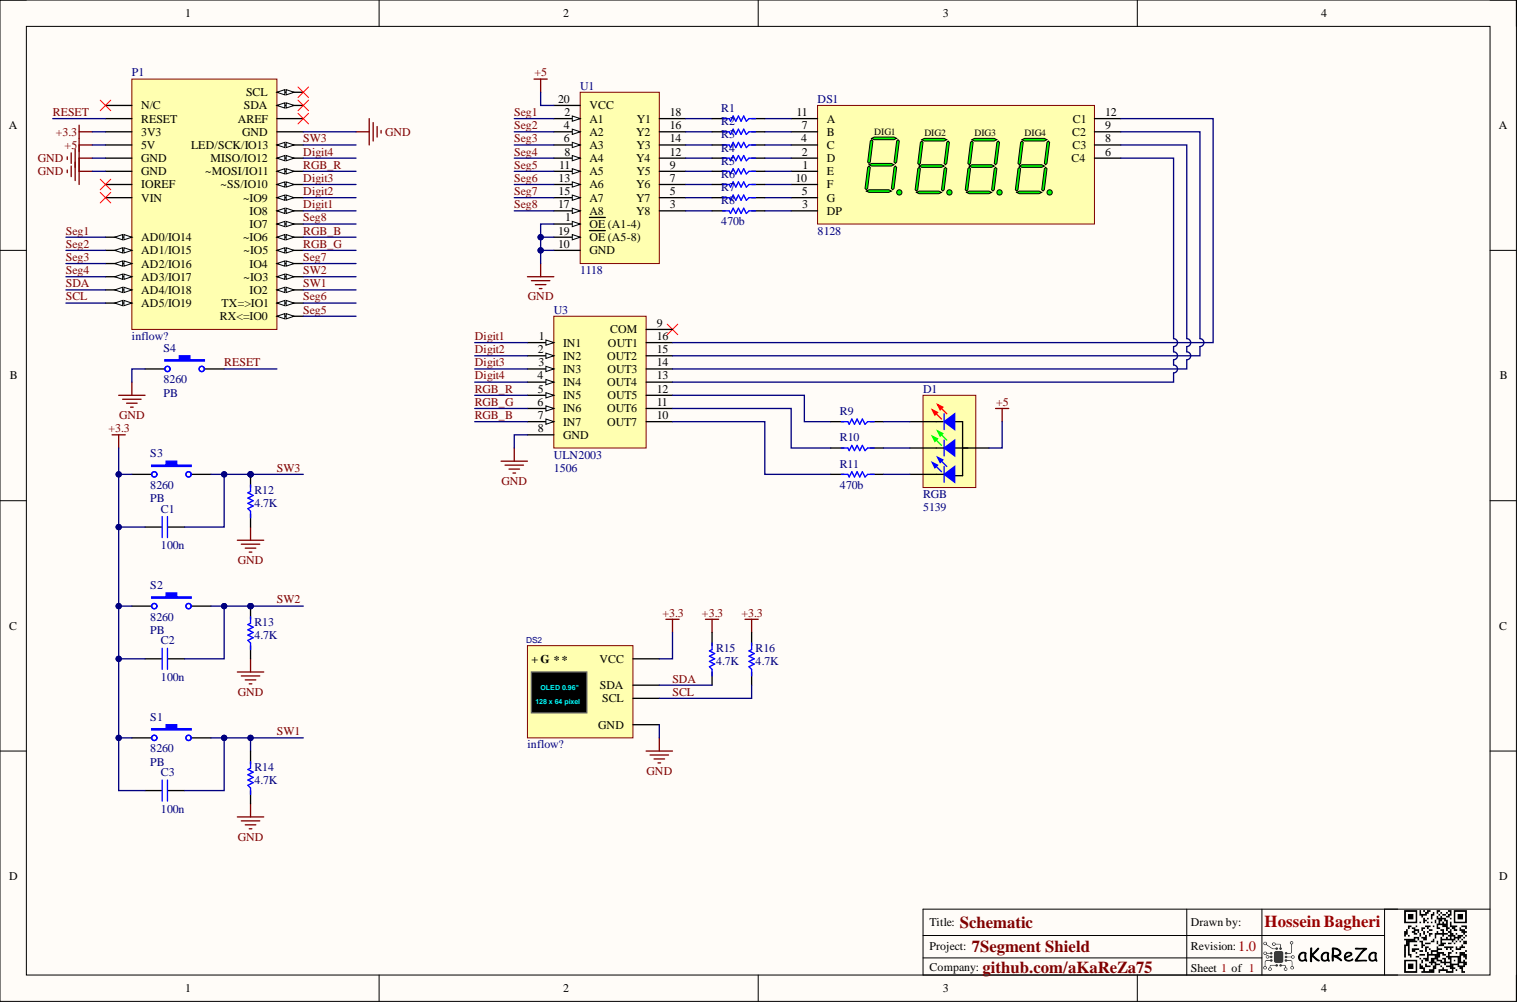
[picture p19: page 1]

1 9 | 8 1 2 8
1 0

1 5
1 4
1 3


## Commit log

2025-02-17 Update Components
    [Arduino_7Segments.PrjPcb, PCB1.PcbDoc, Sheet1.SchDoc]
2025-02-17 update Project
    [Arduino_7Segments.PrjPcb]
2025-03-10 add Documents
    [Arduino_7Segments.PrjPcb, PCB1.PcbDoc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]
2025-03-10 Update documents
    [PCB1.PcbDoc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]
2025-03-11 Update Documents'
    [Arduino_7Segments.PrjPcb, PCB1.PcbDoc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]
2025-07-26 remove misiing outputs
    [Arduino_7Segments.PrjPcb]
